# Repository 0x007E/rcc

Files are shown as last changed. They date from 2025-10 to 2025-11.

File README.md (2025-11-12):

   

# `RCC` - RGB Color Cube



The `RCC` project is based on a pcb with an [ATtiny402](#additional-information) and two [RGB LEDs](#additional-information) that are controlled via SPI-bus. The cube itself is controlled over a single push-button that enables/disables the cube and can be used to setup the color and intensity of the rgb leds.

| Experience | Level |
|:---|:-----:|
| Soldering | ?% |
| Mechanical  | ?% |
| Software | ?% |

# Manual

| Language | File | Description |
|:---:|:---:|:---:|
| English  | [pdf](https://github.com/0x007E/rcc/releases/latest/download/manual.en.pdf) | Assembly of PCB/housing and programming of the RCC |
| German | [pdf](https://github.com/0x007E/rcc/releases/latest/download/manual.de.pdf) | Assembly of PCB/housing and programming of the RCC |

# Simulator

With the [RCC-Simulator](https://0x007e.github.io/rcc-simulator/) different functions (e.g. power-on/-off, ...) can be simulated within a webpage.

# Downloads

| Type | File | Description |
|:---:|:---:|:---|
| Schematic | [pdf](https://github.com/0x007E/rcc/releases/latest/download/schematic.pdf) / [cadlab](https://cadlab.io/project/29642/main/files) | Schematic files |
| Board | [pdf](https://github.com/0x007E/rcc/releases/latest/download/pcb.pdf) / [cadlab](https://cadlab.io/project/29642/main/files) | Board file |
| Drill | [pdf](https://github.com/0x007E/rcc/releases/latest/download/drill.pdf) | Drill file |
| PCB | [zip](https://github.com/0x007E/rcc/releases/latest/download/kicad.zip) / [tar](https://github.com/0x007E/rcc/releases/latest/download/kicad.tar.gz) | KiCAD/Gerber/BoM/Drill files |
| Mechanical | [zip](https://github.com/0x007E/rcc/releases/latest/download/freecad.zip) / [tar](https://github.com/0x007E/rcc/releases/latest/download/freecad.tar.gz) | FreeCAD/Housing and PCB (STEP) files |
| Firmware | [zip](https://github.com/0x007E/rcc/releases/latest/download/firmware.zip) / [tar](https://github.com/0x007E/rcc/releases/latest/download/firmware.tar.gz) | Firmware for ATtiny402 |

# Hardware

There are two parts of the hardware. The pcb and the housing of the `RCC`. The pcb is created with [KiCAD](#additional-information) and the housing with `FreeCAD`. The software is programmed with [Microchip (Atmel) Studio](#additional-information). All files are built with `github actions` so that they are ready for a production environment. The housing is printed with a 3D-printer (`Dremel 3D40`).

## PCB

The circuit board is populated on both sides (Top, Bottom). The best way for soldering the `SMD` components is within a vapor phase soldering system and for the `THT` components with a standard soldering system.

### Top Layer

Top Layer

### Bottom Layer

Bottom Layer

## Mechanical

The housing has a tolerance of `0.2mm` on each side of the case. So the pcb should fit perfectly in the housing. The tolerance can be modified with `FreeCAD` in the `Parameter` Spreadsheet.

### Assembled

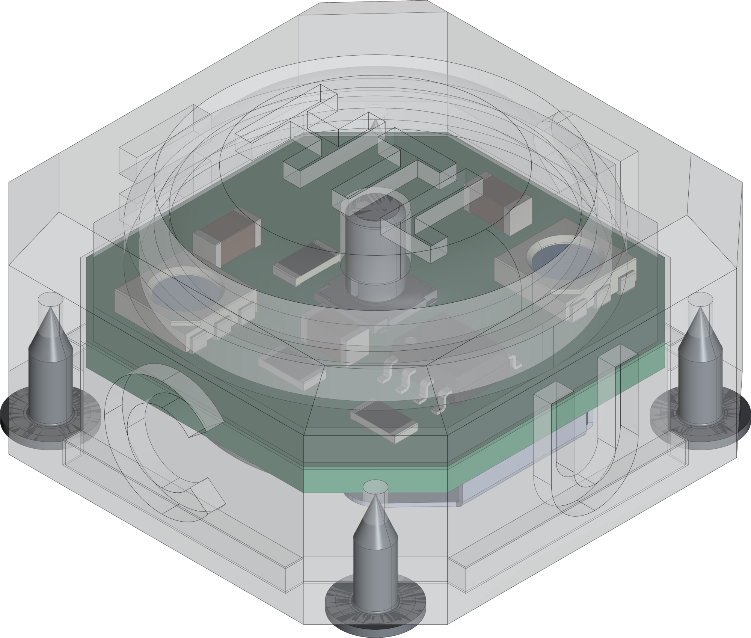
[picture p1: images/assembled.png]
Assembled


#### Exploded

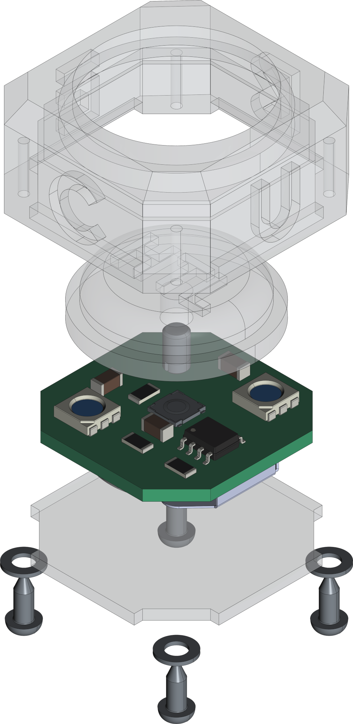
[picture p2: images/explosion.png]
Exploded


# Programming/Setup

The `RCC` is powerd with a `3V` battery (`CR2032`). It can be programmed over [UPDI](#additional-information) on `TP1`. The firmware for the cube can be downloaded in the [download section](#downloads).

``` bash
#                                                          +-----------+      +---------------------+
#                                                          |    U  +---+---+  |                     |
#     +---------------------+                              |    S  |  USB  |--+ +-----------------+ |
#     |                     |                              |    B  +---+---+  | | AVR-Dude        | |
#     |    RCC - Color Cube |         +----------+         |    /      |      | | ~~~~~~~~        | |
#     |                  +--+--+   +--+--+  U    |         |    U      |      | | ~~~~~           | |
#     |              VCC | TP3 +---+ VCC |  P  +--+--+  +--+--+ A      |      | | ~~~~~~~~~~~~    | |
#     |              GND | TP2 +---+ GND |  D  | GND +--+ GND | R      |      | |                 | |
#     |                  +--+--+   +--+--+  I  | VCC +--+ VCC | T      |      | +-----------------+ |
#     |                     |         |        +-----+  +-----+ A      |      |                     |
#     |                  +--+--+   +--+--+     | RxD +--+ RxD | +------+      | Computer            |
#     |             UPDI | TP1 +---+ PDI |     | TxD +--+ TxD | |5V/3V3|      |                     |
#     |                  +--+--+   +--+--+     +--+--+  +--+--+ +------+      +---------------------+
#     +---------------------+         | ADAPTER   |        +----+------+
#                                     +-----------+
```

## FUSES

| Register  | Value  |
|:---:|:---:|
| `WDTCFG`  | `0x00` |
| `BODCFG`  | `0x00` |
| `OSCCFG`  | `0x03` |
| `TCD0CFG` | `0x00` |
| `SYSCFG0` | `0xF5` |
| `SYSCFG1` | `0x00` |
| `APPEND`  | `0x00` |
| `BOOTEND` | `0x00` |

# Software

The leds are controlled by `SPI`. The interface is displayed in the [dataflow](#dataflow-diagram) diagram. There is a pre-configured firmware to use the cube or a library to implement own solutions.

> A documentation of the code can be found here [https://0x007e.github.io/rcc](https://0x007e.github.io/rcc).

## Dataflow diagram

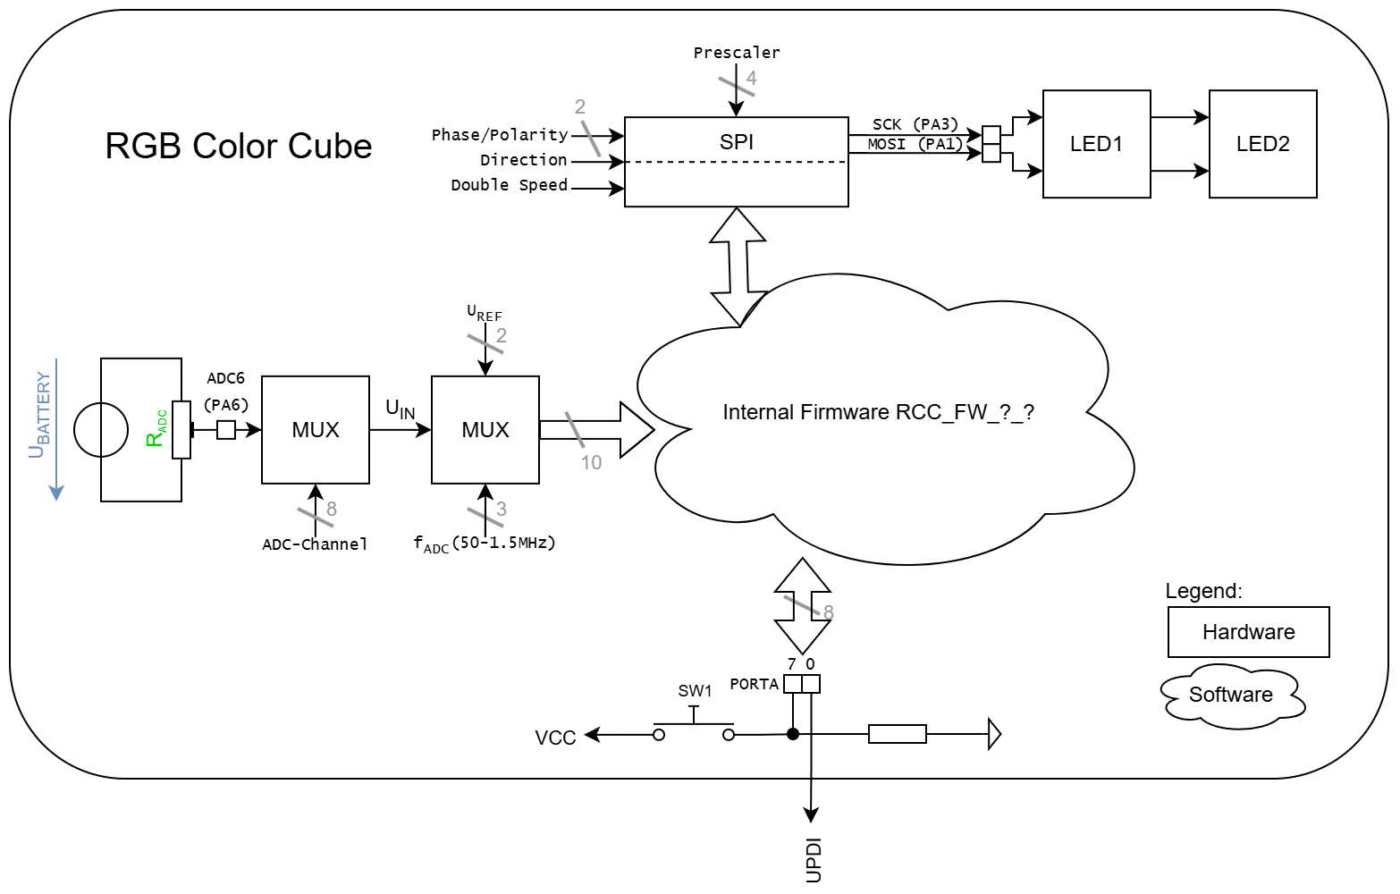
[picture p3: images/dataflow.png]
Dataflow


## Library (`led.h`)

With the attached `led` library it is quiet easy to use the cube for own implementations. To setup the led library for the cube implement the header file.

``` c
#define F_CPU 20000000UL

#include <avr/io.h>
#include <util/delay.h>

#include "./hal/avr0/system/system.h"
#include "./led/led.h"

LED_Data led1  = {
	0x01,
	0x0F,
	0x00,
	0x0A
};

LED_Data led2  = {
	0x01,
	0x00,
	0x0F,
	0x0A
};

int main(void)
{
    system_init();
    led_init();
    // ...

    while(1)
    {
        led_blink(LED_Position_Left | LED_Position_Right_Alternating, led_status_color(LED_Status_Ready, LED_MIN_INTENSITY), LED_Delay_MS_200, 2);

        LED_SOF();
        led_data(led1);
        led_data(led2);
        LED_EOF();

        _delay_ms(2000);
    }
}
```

# Additional Information

| Type | Link | Description |
|:---:|:---:|:---|
| ATtiny402  | [pdf](https://ww1.microchip.com/downloads/en/DeviceDoc/ATtiny202-402-AVR-MCU-with-Core-Independent-Peripherals_and-picoPower-40001969A.pdf) | ATtiny microcontroller |
| T3A33BRG | [pdf](https://mm.digikey.com/Volume0/opasdata/d220001/medias/docus/6794/3147_T3A33BRG-H9C0002X1U1930.pdf) | RGB Color LED |
| Atmel ICE  | [pdf](https://ww1.microchip.com/downloads/en/DeviceDoc/Atmel-ICE_UserGuide.pdf) | Atmel ICE datasheet |
| UPDI | [web](https://github.com/0x007e/updi) | UPDI-Adapter with AVR-Dude |
| Microchip Studio | [web](https://www.microchip.com/en-us/tools-resources/develop/microchip-studio) | Download page for Microchip Studio |
| KiCAD | [web](https://www.kicad.org/) | KiCAD project page |
| FreeCAD | [web](https://www.freecad.org/) | FreeCAD project page |

---

R. GAECHTER

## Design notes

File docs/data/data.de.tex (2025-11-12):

\newcommand{\headerText}{\textbf{HTL-Rankweil}\\\texttt{Abteilung für Elektronik/Informatik}}
\newcommand{\titleLogoCaption}{Zusammengesetzter Cube}
\newcommand{\titleDescription}{\small Das RCC-Projekt basiert auf einer Platine mit einem ATtiny402 und zwei RGB-LEDs, die über den SPI-Bus gesteuert werden. Der Cube selbst wird über einen einzigen Taster gesteuert, der den Cube ein- und ausschaltet und zur Einrichtung der Farbe und Helligkeit der LEDs verwendet werden kann.\\}

\newcommand{\globalimportanttext}{Wichtig:}

\newcommand{\abstracttitle}{Einleitung}
\newcommand{\abstracttext}{
Das \texttt{RCC}-Projekt (RGB LED Color Cube) ist ein eingebettetes System, das einen \texttt{ATtiny402}\footnote{\url{https://link.sunriax.at/MecTz}} Mikrocontroller, welcher zwei RGB-LEDs\footnote{\url{https://link.sunriax.at/nBUNH}} über einen SPI-Bus steuert, verwendet. Das System verfügt über eine Benutzeroberfläche mit einem einzigen Taster, um den \texttt{RCC}-Cube ein- und auszuschalten und die Farbe sowie die Helligkeitseinstellungen anzupassen. Es umfasst ein einfaches Hardware-Design, sowie eine Firmware und Bibliotheken für eine einfache Integration und Anpassung. Das Projekt nutzt KiCAD für das PCB-Design, FreeCAD für das Gehäuse und Microchip Studio für die bereitstellung der Firmware und legt dabei Wert auf Modularität und professionelle Produktionsbereitschaft durch automatisierte Build-Prozesse mit GitHub Actions. Dieses Setup bietet eine kompakte, vielseitige und programmierbare RGB-Beleuchtungslösung, die sich für Prototyping und Bildungszwecke in der Entwicklung von Elektronik- sowie eingebetteten Systemen eignet.
\newline
Die Montage der Leiterplatte erfolgt mit einer halbautomatischen Bestückungsmaschine, um eine präzise und effiziente Bauteilmontage sicherzustellen. Das Löten der Bauteile erfolgt mit einer Dampfphasenlötanalge, die eine gleichmäßige Wärmeverteilung und hochwertige Lötverbindungen gewährleistet. Das Batteriefach wird manuell mit herkömmlichen Lötmethoden (Bleifrei) verlötet. Das Gehäuse wird mittels 3D-Druck hergestellt, was eine schnelle Prototypenerstellung, eine hohe Genauigkeit und feine Details ermöglicht. Darüber hinaus wird die Acrylplatte auf der Unterseite des Gehäuses mit einem CO\textsubscript{2}-Laser-Cutter zugeschnitten und graviert, um präzise Formen und individuelle Oberflächenmarkierungen herzustellen.
\newline
Dieser Prozessablauf garantiert ein professionell montiertes und fertiges Produkt, das automatisierte Fertigungstechniken mit manueller Präzision und fortschrittlichen Fertigungstechnologien kombiniert.
}

\newcommand{\pcbsectiontitle}{Leiterplattenmontage}
\newcommand{\pcbfigureassemblytopcaptiontext}{Leiterplatten Top-Bearbeitungs- und Montagelayout}
\newcommand{\pcbfigureassemblybottomcaptiontext}{Leiterpatten Bottom-Bearbeitungs- und Montagelayout}

\newcommand{\programmersectiontitle}{Firmware-Programmierung}
\newcommand{\programmerfigureprogrammercaptiontext}{Programmer}
\newcommand{\programmerintroductiontext}{Die Verwendung des \texttt{Programmiergeräts} zum Flashen des \texttt{ATtiny402} über die \texttt{UPDI}-Schnittstelle ist unkompliziert. Die erforderliche Software zum Flashen kann über das \texttt{RCC Programming Repository}\footnote{\url{https://github.com/0x007e/rcc_programmer}} heruntergeladen werden. Über die USB-to-UART-Brücke wird die Firmware auf den Mikrocontroller übertragen. Die Anwendung selbst bietet eine einfache Benutzeroberfläche, um die Firmware auf den \texttt{RCC} zu übertragen. Die Farbe und die Intensität der LEDs kann innerhalb der Anwendung angepasst werden.}
\newcommand{\programmertabledownloadlinkstitle}{RCC - Programmier-Software (Windows x64)}
\newcommand{\programmertabledownloadlinksclickoncetext}{ClickOnce-Installer, der automatisch aktualisiert wird, wenn neue Versionen verfügbar sind.}
\newcommand{\programmertabledownloadlinksportabletext}{Portable Version, die ohne Installation ausgeführt werden kann, aber manuell aktualisiert werden muss.}
\newcommand{\programmertabledownloadlinkscaptiontext}{Download-Links}
\newcommand{\programmerfigureinterfacecaptiontext}{Programmierschnittstelle}
\newcommand{\programmertablenoticetext}{Der \textbf{RCC}-Cube wird durch die USB-UART-Brücke (über die \texttt{Pogo}-Pins) mit \texttt{3V3} versorgt und benötigt keine Batterie. Es ist sicherzustellen, dass das \textbf{RCC}-Gerät \textbf{\textcolor{red}{nicht mit Batterie betrieben wird, um Schäden am Gerät zu vermeiden!}}}
\newcommand{\programmertablenoticecaption}{Programmiergerät-Hinweis}
\newcommand{\programmertableselfmadeupdititle}{Verwenden von externen UPDI-Adaptern}
\newcommand{\programmertableselfmadeupditext}{Ein selbstgebauter UPDI-Adapter kann auch innerhalb einer FT232 USB-to-UART-Brücke oder eines ähnlichen Moduls gemäß den Schaltplänen auf der \texttt{UPDI}\footnote{\url{https://github.com/0x007e/updi}}-Projektseite verwendet werden. Die Verbindungsanordnung finden Sie auf der Programmierer-Projektseite\footnote{\url{https://github.com/0x007e/rcc_programmer}} selbst.}
\newcommand{\programmertableselfmadeupdicaption}{UPDI-Adapter-Informationen}

\newcommand{\mechanicalsectiontitle}{Mechanische Montage}
\newcommand{\mechanicalintroductiontext}{Die mechanische Montage erfolgt durch das Zusammenfügen der 3D-gedruckten Gehäuseteile mit der lasergeschnittenen Acrylplatte. Die Leiterplatte wird mit den integrierten Montageschrauben im Gehäuse befestigt. Die Batterie muss montiert werden, bevor die Leiterplatte im Gehäuse platziert wird.}
\newcommand{\mechanicalsubsectionsteps}{Notwendige Schritte:}
\newcommand{\mechanicalfigurecaptionexplosion}{Explosionsansicht der mechanischen Montage}

\newcommand{\mechanicaltextfile}{./data/mechanicaltext.de.csv}
\newcommand{\mechanicalstepsfile}{./data/mechanicalsteps.de.csv}

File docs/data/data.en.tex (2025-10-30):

\newcommand{\headerText}{\textbf{HTL-Rankweil}\\\texttt{Department of Electronics/Informatics}}
\newcommand{\titleLogoCaption}{Assembled Cube}
\newcommand{\titleDescription}{\small The RCC project is based on a pcb with an ATtiny402 and two RGB LEDs that are controlled via SPI-bus. The cube itself is controlled over a single push-button that enables/disables the cube and can be used to setup the color and intensity of the leds.\\}

\newcommand{\globalimportanttext}{Important:}

\newcommand{\abstracttitle}{Abstract}
\newcommand{\abstracttext}{
The \texttt{RCC} (RGB LED Color Cube) project is an embedded system based on a PCB with an \texttt{ATtiny402}\footnote{\url{https://link.sunriax.at/MecTz}} microcontroller controlling two RGB LEDs\footnote{\url{https://link.sunriax.at/nBUNH}} via SPI communication. The system features a user interface with a single push-button to toggle the cube and adjust its color and brightness settings. It includes comprehensive hardware designs, firmware, and libraries for easy integration and customization. The project leverages KiCAD for PCB design, FreeCAD for housing, and Microchip Studio for firmware development, emphasizing modularity and professional production readiness through automated build processes using GitHub Actions. This setup provides a compact, versatile, and programmable RGB lighting solution suitable for prototyping and educational purposes in electronic and embedded systems development.
\newline
The assembly of the PCB is carried out using a semi-automatic placement machine to ensure precise and efficient component mounting. Soldering of the PCB components is performed with a vapor phase soldering system, which provides uniform heat distribution and high-quality solder joints. The battery holder is soldered manually using conventional soldering methods to allow for careful handling of this specific component. The enclosure is produced by 3D printing, enabling rapid prototyping with high accuracy and fine detail. Additionally, the acrylic plate on the bottom side of the enclosure is cut and engraved using a CO\textsubscript{2} laser cutter, ensuring precise shaping and custom surface markings.
\newline
This process guarantees a professionally assembled and finished product combining automated manufacturing techniques with manual precision and advanced fabrication technologies.
}

\newcommand{\pcbsectiontitle}{PCB Assembly}
\newcommand{\pcbfigureassemblytopcaptiontext}{PCB Top fabrication and assembly layout}
\newcommand{\pcbfigureassemblybottomcaptiontext}{PCB Bottom fabrication and assembly layout}

\newcommand{\programmersectiontitle}{Firmware programming}
\newcommand{\programmerfigureprogrammercaptiontext}{Programmer}
\newcommand{\programmerintroductiontext}{Using the \texttt{programming tool} to flash the \texttt{ATtiny402} via \texttt{UPDI} interface is straightforward. Just download and install the required software and flash it with the \texttt{RCC Programming Toolkit}\footnote{\url{https://github.com/0x007e/rcc_programmer}} over the implemented USB-to-UART bridge in the \texttt{RCC-Programmer}. The \texttt{programming tool} itself can be installed or used as a portable application. The application itself provides a simple user interface to flash the firmware onto the \texttt{RCC} device. Therefore the color and intensitry of the LEDs can be adjusted within the application before flashing it onto the device.}
\newcommand{\programmertabledownloadlinkstitle}{RCC - Programming Software (Windows x64)}
\newcommand{\programmertabledownloadlinksclickoncetext}{ClickOnce installer that updates automatically when new versions are available.}
\newcommand{\programmertabledownloadlinksportabletext}{Portable version that can be run without installation but needs to be updated manually.}
\newcommand{\programmertabledownloadlinkscaptiontext}{Download Links}
\newcommand{\programmerfigureinterfacecaptiontext}{Programming Interface}
\newcommand{\programmertablenoticetext}{The \textbf{RCC}-Cube is powered through the USB-UART bridge (through the \texttt{Pogo}-pins) with \texttt{3V3} and does not require a battery. It must be ensured that the \textbf{RCC} device is \textbf{\textcolor{red}{not powered by battery to avoid damage to the device!}}}
\newcommand{\programmertablenoticecaption}{Programmer Notice}
\newcommand{\programmertableselfmadeupdititle}{Using of external UPDI-Adapters}
\newcommand{\programmertableselfmadeupditext}{A selfmade UPDI adapter can also be used within an FT232 USB-to-UART bridge or a similar module according to the schematics provided on the \texttt{UPDI}\footnote{\url{https://github.com/0x007e/updi}} project page. The connection setup can be found on the programmer project site\footnote{\url{https://github.com/0x007e/rcc_programmer}} itself.}
\newcommand{\programmertableselfmadeupdicaption}{UPDI-Adapter Information}

\newcommand{\mechanicalsectiontitle}{Mechanical Assembly}
\newcommand{\mechanicalintroductiontext}{The mechanical assembly is done by assembling the 3D printed enclosure parts together with the laser-cut acrylic plate. The PCB is mounted inside the enclosure using the integrated mounting features. The battery has to be mounted before the PCB is placed inside the enclosure.}
\newcommand{\mechanicalsubsectionsteps}{Necessary steps:}
\newcommand{\mechanicalfigurecaptionexplosion}{Exploded view of the mechanical assembly}

\newcommand{\mechanicaltextfile}{./data/mechanicaltext.en.csv}
\newcommand{\mechanicalstepsfile}{./data/mechanicalsteps.en.csv}

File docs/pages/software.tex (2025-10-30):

\newcounter{softwaretnotecounter}

\iflanguage{ngerman}{
  \newcommand{\softwaresectiontitle}{Verwendete Software}
  \newcommand{\softwaretableimage}{Abbildung}
  \newcommand{\softwaretablename}{Name}
  \newcommand{\softwaretabledescription}{Beschreibung}
  \newcommand{\softwaretablecaptiontext}{Softwarekomponenten für das Projekt}

  \newcommand{\softwareltspicetext}{Simulationssoftware für elektronische Schaltungen, weitverbreitet zum Entwurf und Testen von Schaltungen.}
  \newcommand{\softwaremicrochipstudiotext}{Entwicklungsumgebung (IDE) zur Programmierung von Mikrocontrollern, insbesondere AVR und ARM.}
  \newcommand{\softwarefreecadtext}{Open-Source CAD-Software für 3D-Modellierung, geeignet für technische Konstruktionen und Design.}
  \newcommand{\softwarekicadtext}{Open-Source PCB-Design-Software, geeignet für die Erstellung von Leiterplattenlayouts.}
  \newcommand{\softwaredremeldigilabslicertext}{Software zum Vorbereiten und Slicen von 3D-Druck-Modellen, speziell für Dremel 3D-Drucker optimiert.}

  \newcommand{\softwarelogotext}{Die abgebildeten Logos sind markenrechtlich geschützte Symbole. Sie werden in dieser Dokumentation ausschließlich zur Identifikation der jeweiligen Softwareprodukte verwendet, ohne Werbeabsicht.}
}{
  \newcommand{\softwaresectiontitle}{Used Software}
  \newcommand{\softwaretableimage}{Figure}
  \newcommand{\softwaretablename}{Name}
  \newcommand{\softwaretabledescription}{Description}
  \newcommand{\softwaretablecaptiontext}{Software components for the project}

  \newcommand{\softwareltspicetext}{Simulation software for electronic circuits, widely used for designing and testing circuits.}
  \newcommand{\softwaremicrochipstudiotext}{Development environment (IDE) for programming microcontrollers, especially AVR and ARM.}
  \newcommand{\softwarefreecadtext}{Open-source CAD software for 3D modeling, suitable for technical constructions and design.}
  \newcommand{\softwarekicadtext}{Open-source PCB design software, suitable for creating printed circuit board layouts.}
  \newcommand{\softwaredremeldigilabslicertext}{Software for preparing and slicing 3D print models, specifically optimized for Dremel 3D printers.}

  \newcommand{\softwarelogotext}{The logos shown are protected by trademark law. They are used in this documentation solely for the identification of the respective software products, without any advertising intent.}
}

\section*{\softwaresectiontitle}
\begin{table}[!ht]
  \renewcommand{\arraystretch}{1.3}
  \centering
  \begin{threeparttable}
    \begin{tabularx}{\linewidth}{|M{2.4cm}|M{2.2cm}|X|}
      \hline
      \rowcolor{gray!20}
      \textbf{\softwaretableimage\tnote{*}} & \textbf{\softwaretablename} & \textbf{\softwaretabledescription} \\
      \hline
\ifsoftwarepagelineartechnology
      \stepcounter{softwaretnotecounter}
      \raisebox{-.25\height}{\includesvg[width=1.6cm,inkscapelatex=false]{./logo/linear_technology}} &
      LT-Spice\tnote{(\thesoftwaretnotecounter)} &
      \softwareltspicetext\\
      \hline
\fi
\ifsoftwarepagemicrochipstudio
      \stepcounter{softwaretnotecounter}
      \raisebox{-.25\height}{\includesvg[width=1.6cm,inkscapelatex=false]{./logo/microchip}} &
      Microchip Studio\tnote{(\thesoftwaretnotecounter)} &
      \softwaremicrochipstudiotext\\
      \hline
\fi
\ifsoftwarepagefreecad
      \stepcounter{softwaretnotecounter}
      \raisebox{-.25\height}{\includesvg[width=0.65cm,inkscapelatex=false]{./logo/freecad}} &
      FreeCAD\tnote{(\thesoftwaretnotecounter)} &
      \softwarefreecadtext\\
      \hline
\fi
\ifsoftwarepagekicad
      \stepcounter{softwaretnotecounter}
      \raisebox{-.25\height}{\includesvg[width=0.65cm,inkscapelatex=false]{./logo/kicad}} &
      KiCAD\tnote{(\thesoftwaretnotecounter)} &
      \softwarekicadtext\\
      \hline
\fi
\ifsoftwarepagedremeldigilabslicer
      \stepcounter{softwaretnotecounter}
      \raisebox{-.25\height}{\includesvg[width=1.6cm,inkscapelatex=false]{./logo/dremel}} &
      Dremel 3D DigiLab Slicer\tnote{(\thesoftwaretnotecounter)} &
      \softwaredremeldigilabslicertext\\
      \hline
\fi
    \end{tabularx}
    \caption{\softwaretablecaptiontext}
    \label{tab:software-programme}
    \begin{tablenotes}
      \footnotesize
      \item[*] \softwarelogotext
      \item[~]
\setcounter{softwaretnotecounter}{0}
\ifsoftwarepagelineartechnology
      \stepcounter{softwaretnotecounter}
      \item[(\thesoftwaretnotecounter)] \url{https://www.analog.com/en/resources/design-tools-and-calculators.html}
\fi
\ifsoftwarepagemicrochipstudio
      \stepcounter{softwaretnotecounter}
      \item[(\thesoftwaretnotecounter)] \url{https://www.microchip.com/en-us/tools-resources/develop/microchip-studio}
\fi
\ifsoftwarepagefreecad
      \stepcounter{softwaretnotecounter}
      \item[(\thesoftwaretnotecounter)] \url{https://www.freecad.org/downloads.php}
\fi
\ifsoftwarepagekicad
      \stepcounter{softwaretnotecounter}
      \item[(\thesoftwaretnotecounter)] \url{https://www.kicad.org/download/}
\fi
\ifsoftwarepagedremeldigilabslicer
      \stepcounter{softwaretnotecounter}
      \item[(\thesoftwaretnotecounter)] \url{https://www.dremel.com/at/de/digilab/3d-druckersoftware}  
\fi
    \end{tablenotes}
  \end{threeparttable}
\end{table}

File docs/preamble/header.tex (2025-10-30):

% Paket für Kopf- und Fußzeilen
\usepackage[automark,headsepline=0.4pt:1.0\textwidth,footsepline=0.4pt:1.0\textwidth]{scrlayer-scrpage}
% Paket für Gesamtseitenzahl
\usepackage{lastpage}

\pagestyle{scrheadings}     % Kopf- und Fußzeilen-Stil setzen

% Standard-Stile von Kopf- und Fußzeilen entfernen
\clearpairofpagestyles

\ihead{}
\chead{}
\ohead{
  \parbox[t]{15cm}{
    \raggedleft
    \headerText
  }
}

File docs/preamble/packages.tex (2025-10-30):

% Sprach- und Kodierungspakete
\usepackage[utf8]{inputenc}
\usepackage[english,ngerman]{babel}
\usepackage[T1]{fontenc}
\usepackage{graphicx}
\usepackage{expl3,xparse}

% Seitenränder
\usepackage[a4paper,margin=2.5cm,top=80pt,headheight=55pt,headsep=10pt,footskip=35pt]{geometry}

% Zeilenabstand
%\usepackage{setspace}
\usepackage[onehalfspacing]{setspace}
\usepackage{array}

\usepackage[colorlinks=true,linkcolor=black,urlcolor=blue,citecolor=black]{hyperref}
\usepackage{url}
\usepackage[nolinks]{qrcode}

\usepackage[printonlyused]{acronym}
\usepackage{tabularx}
\usepackage{tablefootnote}
\usepackage{multirow}
\usepackage{wrapfig}
\usepackage{threeparttable}
\usepackage[table]{xcolor}
\usepackage{tikz}
\usepackage{microtype}
\usepackage{svg}
\usepackage{pifont}

\usepackage{caption}

\usepackage{enumitem}
\setlist[itemize]{itemsep=0.025em}

\usepackage{csquotes}
\usepackage[style=apa, backend=biber]{biblatex}
\addbibresource{./literature.bib}

\usepackage[l3]{csvsimple}

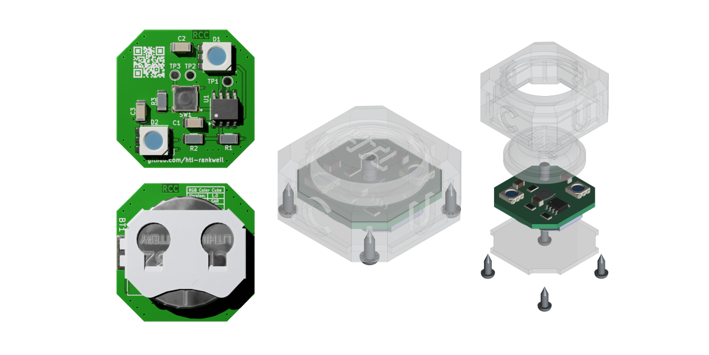
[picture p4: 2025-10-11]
images/social.png

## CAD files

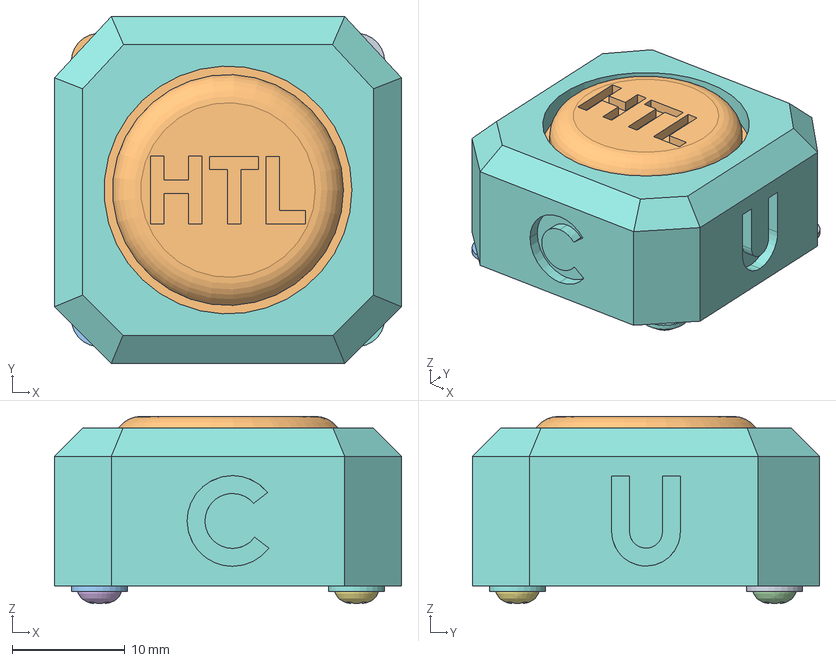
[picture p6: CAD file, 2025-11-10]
mechanical/housing.FCStd
30.8 x 30.8 x 16.6 mm
Pcb_1096
R2_R_1206_3216Metric_a244ae71ee7f
D2_LED_RGB_5050_6_3082613c1204
C2_C_1206_3216Metric_b2c0b2178a0f
C3_C_1206_3216Metric_2d6a083c182e
U1_SOIC_8_39x49mm_P127mm_ced3e6da737e
SW1_1_b49bc00616b6
R3_R_1206_3216Metric_352e77470e97
C1_C_1206_3216Metric_55e30c71a8e1
R1_R_1206_3216Metric_4fa9a57fca02
D1_LED_RGB_5050_6_e07a5316f1e2
BH-67D-5_BH-67D-5
Acrylglass
Button
M3x5-Screw
ST2.2x6.5-Screw
ST2.2x6.5-Screw493
ST2.2x6.5-Screw494
ST2.2x6.5-Screw495
M2.5-Washer
M2.5-Washer022
M2.5-Washer023
M2.5-Washer024

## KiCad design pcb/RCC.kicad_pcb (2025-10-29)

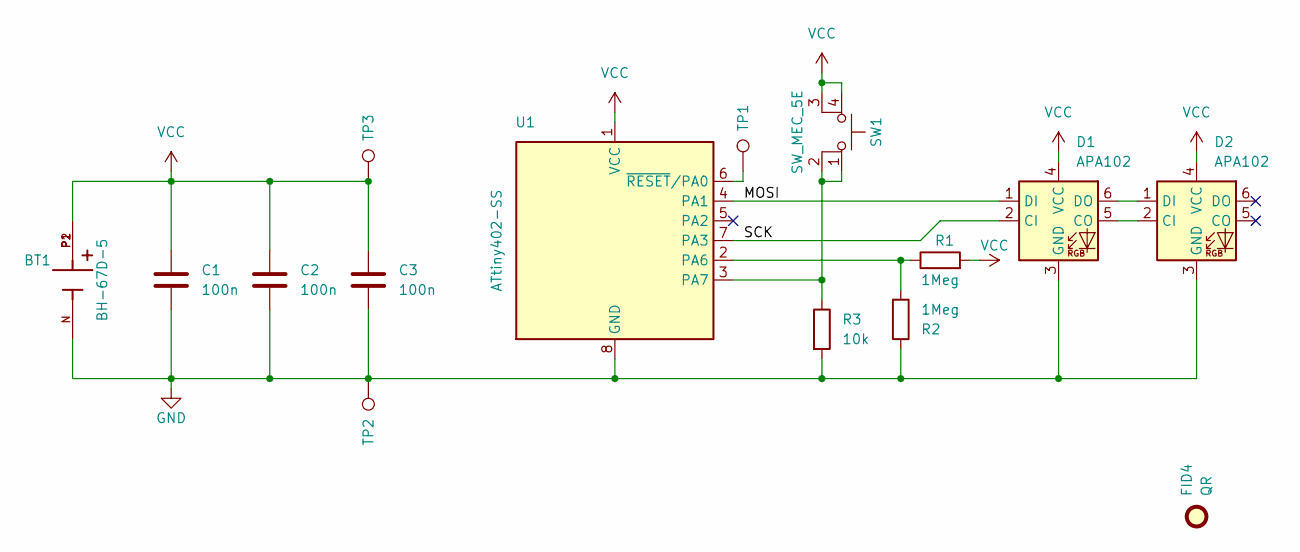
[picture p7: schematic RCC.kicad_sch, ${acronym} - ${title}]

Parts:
BT1: BH-67D-5; BAT_BH-67D-5
C1, C2, C3: 100n; C_1206_3216Metric
D1, D2: APA102; LED_RGB_5050-6
FID4: QR; QR_0x007e_small
R1, R2: 1Meg; R_1206_3216Metric
R3: 10k; R_1206_3216Metric
SW1: SW_MEC_5E; SW_PTS530_GK055_SMTR_LFS
TP1, TP2, TP3: TestPoint; TestPoint_Pad_D1.5mm
U1: ATtiny402-SS; SOIC-8_3.9x4.9mm_P1.27mm

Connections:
/MOSI: D1.1 (DI), U1.4 (PA1)
/SCK: D1.2 (CI), U1.7 (PA3)
GND: BT1.N, C1.2, C2.2, C3.2, D1.3 (GND), D2.3 (GND), R2.1, R3.2, TP2.1, U1.8 (GND)
unnamed: D1.5 (CO), D2.2 (CI)
unnamed: D1.6 (DO), D2.1 (DI)
unnamed: R1.1, R2.2, U1.2 (PA6)
unnamed: R3.1, SW1.1, SW1.2, U1.3 (PA7)
unnamed: TP1.1, U1.6 (~RESET/PA0)
VCC: BT1.P1, BT1.P2, C1.1, C2.1, C3.1, D1.4 (VCC), D2.4 (VCC), R1.2, SW1.3 (K), SW1.4 (A), TP3.1, U1.1 (VCC)

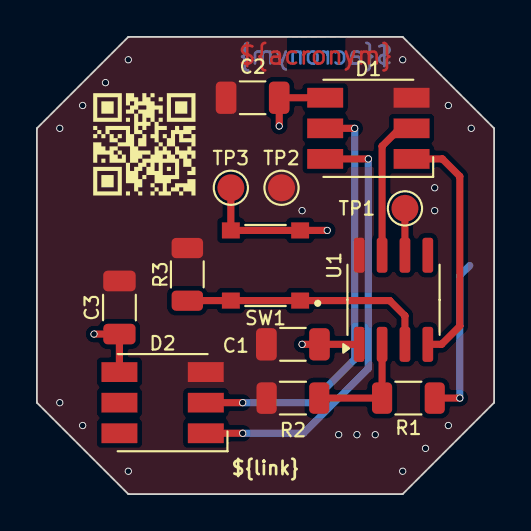
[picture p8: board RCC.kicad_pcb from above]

Board: 2 copper layers, 25.4 x 25.4 mm, 15 parts (1 on the bottom side), 9 nets.

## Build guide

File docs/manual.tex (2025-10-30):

\documentclass[a4paper,12pt]{scrartcl}

\input{./preamble/packages.tex}
\input{./preamble/branch.tex}

\usepackage{listings}

% Globale Parameter
\setlength{\parindent}{0pt} % Kein Einrücken am Anfang eines Absatzes
\newcommand{\documentAuthor}{R. GÄCHTER}

% Header-Parameter
\headertrue           % Header aktivieren
  \newcommand{\headerLogo}{./images/htl.png}

% Footer-Parameter
\footertrue           % Footer aktivieren
  \newcommand{\footerAuthor}{\documentAuthor}
  \newcommand{\footerVersion}{1.0}

% Page-Parameter
% \acronymspagetrue         % Acronyme aktivieren
% \tableofcontentspagetrue  % Inhaltsverzeichnis aktivieren
\listoffigurespagetrue    % Abbildungsverzeichnis aktivieren
\listoftablespagetrue     % Tabellenverzeichnis aktivieren
% \bibliographypagetrue     % Literaturverzeichnis aktivieren

% Titlepage-Parameter
\titlepagetrue                  % Titelblatt aktivieren
\titlepageqrcodetrue            % QR-Code auf dem Titelblatt aktivieren
% \blankpageaftertitlepagetrue  % Leerseite nach dem Titelblatt aktivieren
  \newcommand{\titleHeadline}{RCC - RGB LED Color Cube}
  \newcommand{\titleLogo}{./images/assembled.png}
  \newcommand{\titleLogoWidth}{0.35}
  \newcommand{\titleRepository}{https://github.com/0x007e/rcc}

% Softwarepage-Parameter
\softwarepagetrue     % Software-Seite aktivieren
  % \softwarepagelineartechnologytrue
  \softwarepagemicrochipstudiotrue
  \softwarepagefreecadtrue
  \softwarepagekicadtrue
  % \softwarepagedremeldigilabslicertrue

\input{./preamble/tabular.tex}
\input{./preamble/commands.tex}

\ifheader
  \input{./preamble/header.tex}
\fi

\iffooter
  \input{./preamble/footer.tex}
\fi

% ##########################################################################

\begin{document}

% \selectlanguage{ngerman}
% \selectlanguage{english}

\renewcommand{\tablename}{Tab.}

\iflanguage{ngerman}{
  \renewcommand{\figurename}{Abb.}
  \input{./data/data.de.tex}
}{
  \renewcommand{\figurename}{Fig.}
  \input{./data/data.en.tex}
}

\iftitlepage
  \input{./pages/titlepage.tex}
  \maketitle

  \thispagestyle{empty}
  \newpage

  \ifblankpageaftertitlepage
    ~
    \thispagestyle{empty}
    \newpage
  \fi
\fi

\ifsoftwarepage
  \input{./pages/software.tex}

  \thispagestyle{empty}
  \newpage
\fi

\section*{\abstracttitle}
\abstracttext

\thispagestyle{empty}
\newpage

\setcounter{page}{1}

\noindent\hfill\texttt{GAR@\today|\jobname.pdf}
\vspace{-25pt}

\section{\pcbsectiontitle}

\begin{figure}[!htbp]
  \vspace{-20pt}
  \centering
  
  \caption{\pcbfigureassemblytopcaptiontext}
  \label{fig:pcb-top-assembly}
\end{figure}
\newpage

\begin{figure}[!htbp]
  \centering
  
  \caption{\pcbfigureassemblybottomcaptiontext}
  \label{fig:pcb-bottom-assembly}
\end{figure}
\newpage

\section{\programmersectiontitle}

\begin{wrapfigure}{r}{0.25\textwidth}
  \vspace{-50pt}
  
  \caption{\programmerfigureprogrammercaptiontext}
  \label{fig:rcc-programmer-image}
\end{wrapfigure}

\programmerintroductiontext

\begin{table}[!htbp]
  \renewcommand{\arraystretch}{1.2}
  \noindent
  \begin{minipage}{\textwidth}
    \begin{tabularx}{\textwidth}{|c|c|X|}
      \hline
      \rowcolor{gray!20}
      \multicolumn{3}{|c|}{\textbf{\programmertabledownloadlinkstitle}} \\
      \hline
      \multirow{2}{*}{
        \raisebox{-.5\height}{
          
        }
      } & 
      \href{https://0x007e.github.io/rcc_programmer/clickonce/setup.exe}{\textbf{Installer}}\footnote{\url{https://0x007e.github.io/rcc_programmer/clickonce/setup.exe}} &
      \programmertabledownloadlinksclickoncetext \\
      \cline{2-3}
       & \href{https://github.com/0x007E/rcc_programmer/releases/latest/download/programmer.zip}{\textbf{Portable}}\footnote{\url{https://github.com/0x007E/rcc_programmer/releases/latest/download/programmer.zip}} &
      \programmertabledownloadlinksportabletext \\
      \hline
    \end{tabularx}
    \caption{\programmertabledownloadlinkscaptiontext}
    \label{tab:rcc-programming-download-links}
  \end{minipage}
\end{table}

\vspace{-15pt}
\begin{table}[!htbp]
  \renewcommand{\arraystretch}{1.2}
  \noindent
  \begin{minipage}[t]{0.55\textwidth}
    \vspace{0pt}
    \centering
    
    \caption{\programmerfigureinterfacecaptiontext}
    \label{fig:rcc-programming-interface}
  \end{minipage}%
  \hfill
  \begin{minipage}[t]{0.42\textwidth}
    \vspace{0pt}
    \centering
    \begin{tabularx}{\textwidth}{|M{0.85cm}|X|}
      \hline
      \rowcolor{gray!20}
      \raisebox{-.25\height}{\includesvg[height=0.55cm,inkscapelatex=false]{./symbol/warning}} & \textbf{\globalimportanttext} \\
      \hline
      \multicolumn{2}{|p{\dimexpr\textwidth-2\tabcolsep}|}{\programmertablenoticetext} \\
      \hline
    \end{tabularx}
    \caption{\programmertablenoticecaption}
    \label{tab:rcc-programmer-notice}
  \end{minipage}
\end{table}

\vspace{-10pt}
\begin{table}[!ht]
  \renewcommand{\arraystretch}{1.2}
  \centering
  \begin{tabularx}{\textwidth}{|M{0.85cm}|X|}
      \hline
      \rowcolor{gray!20}
      \raisebox{-.25\height}{\includesvg[height=0.55cm,inkscapelatex=false]{./symbol/info}} & \textbf{\programmertableselfmadeupdititle} \\
      \hline
      \multicolumn{2}{|p{\dimexpr\textwidth-2\tabcolsep}|}{\programmertableselfmadeupditext} \\
  \hline
  \end{tabularx}
  \caption{\programmertableselfmadeupdicaption}
  \label{tab:rcc-programmer-selfmade-updi}
\end{table}

\newpage

\section{\mechanicalsectiontitle}
\mechanicalintroductiontext
\subsection*{\mechanicalsubsectionsteps}

\begin{itemize}
  \setlength\itemsep{-5pt}
  \setlength\parskip{5pt}
  \csvreader[head to column names]{\mechanicalstepsfile}{}
  {
    \item \itemtext
  }
\end{itemize}

\begin{figure}[htb]
  \vspace{-15pt}
  \centering
  
  \caption{\mechanicalfigurecaptionexplosion}
  \label{fig:mechanical-explosion}
\end{figure}
\newpage

\iflistoffigurespage
  \listoffigures
\fi

\iflistoftablespage
  \listoftables
\fi

\iflistoffigurespage
  \thispagestyle{empty}
  \newpage
\else
  \iflistoftablespage
    \thispagestyle{empty}
    \newpage
  \fi
\fi

\end{document}

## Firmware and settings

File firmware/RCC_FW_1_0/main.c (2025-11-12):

/**
 * @file main.c
 * @brief Main firmware file for RCC RGB LED Color Cube on AVR.
 *
 * This source file implements the main control flow and event handling for the RCC embedded system. It manages system initialization, LEDs and battery management, interrupt handling, EEPROM operations, and execution of user commands triggered by button inputs. Key functionalities include timed LED blinking, system-wide power management including shutdown and restart logic, and processing of button press events for dynamic LED control.
 *
 * @author g.raf
 * @date 2025-12-10
 * @version 1.0 Release
 * @copyright
 * Copyright (c) 2025 g.raf
 * Released under the GPLv3 License. (see LICENSE in repository)
 *
 * @note This file is part of a larger AVR embedded project subject to the license specified in the repository. For updates and complete revision history, see the GitHub repository.
 *
 * @see https://github.com/0x007e/rcc "RCC - RGB LED Color Cube"
 */

#include "main.h"

static unsigned int switch_count = 0UL;

char EEMEM description[] = "RCC Firmware v1.0 by";
char EEMEM author[] = "R. GAECHTER";
char EEMEM copyright[] = "Copyright 2025 g.raf engineering";
char EEMEM github[] = "github.com/0x007e/rcc";

LED_Data EEMEM ee_led1  = {
	0x03,
	0x00,
	0xFF,
	0xFF
};

LED_Data EEMEM ee_led2  = {
	0x03,
	0xFF,
	0x00,
	0xFF
};

LED_Data led1, led2;

/**
 * @brief Interrupt Service Routine for PORTA pin change or event.
 *
 * This ISR handles the interrupt triggered by an event on PORTA pins. In this implementation, it only clears the interrupt flag for PIN7 on PORTA to acknowledge and allow further interrupts. This prevents the interrupt from continuously retriggering.
 *
 * @note The ISR is registered for the PORTA interrupt vector and is executed automatically upon the corresponding hardware interrupt and is necessary for system wakeup after deep sleep.
 */
ISR(PORTA_PORT_vect)
{	
	PORTA.INTFLAGS = PORT_INT_7_bm;
}

volatile unsigned long systick;

/**
 * @brief Timer/Counter Overflow Interrupt Service Routine.
 *
 * This ISR is called when the Timer/Counter overflows. It increments the global millisecond tick counter `systick` used for system timing. The interrupt flag for the overflow is cleared to allow subsequent interrupts.
 *
 * @note Ensure the timer is properly configured and overflow interrupts are enabled for this routine to be executed correctly.
 */
ISR(TCA0_OVF_vect)
{
    systick++;
	TCA0.SINGLE.INTFLAGS = TCA_SINGLE_OVF_bm;
}

/**
 * @brief Initializes Timer/Counter in single mode with overflow interrupt.
 *
 * This function configures the TCA0 timer as a 16-bit timer operating in single mode. It sets the overflow interrupt enable bit, loads the period register with a predefined value, and starts the timer with a clock prescaler of divide-by-8.
 *
 * @details
 * The timer will generate an interrupt when the counter overflows at the value in the PER register. The overflow interrupt is enabled to allow time-based events or system ticks. The clock source selection and enabling the timer starts the counting immediately.
 */
static void timer_init(void)
{	
	TCA0.SINGLE.INTCTRL |= TCA_SINGLE_OVF_bm;
	TCA0.SINGLE.PER = 0x04E1;
	TCA0.SINGLE.CTRLA |= TCA_SINGLE_CLKSEL_DIV8_gc | TCA_SINGLE_ENABLE_bm;
}

/**
 * @brief Disables Timer/Counter and clears its overflow interrupt.
 *
 * This function disables the overflow interrupt for Timer/Counter TCA0, stops the timer by clearing the clock select and enable bits, and clears any pending overflow interrupt flags.
 *
 * @details
 * Disabling the timer halts counting and prevents further interrupt triggers. The interrupt flag is cleared to avoid immediately re-entering the ISR. This should be called when timer-based operations need to be stopped safely.
 */
static void timer_disable(void)
{
	TCA0.SINGLE.INTCTRL &= ~TCA_SINGLE_OVF_bm;
	TCA0.SINGLE.CTRLA = ~(TCA_SINGLE_CLKSEL_DIV8_gc | TCA_SINGLE_ENABLE_bm);
	TCA0.SINGLE.INTFLAGS = TCA_SINGLE_OVF_bm;
}

/**
 * @brief Performs a controlled system shutdown and restarts the microcontroller.
 *
 * This function disables timers, battery and LED subsystems, configures PORTA pins for low power, sets the microcontroller into the power-down sleep mode to minimize energy consumption, and then triggers a software reset to restart the system.
 *
 * @details
 * - Disables the Timer/Counter to stop timing interrupts
 * - Powers down battery and LED to save energy
 * - Configures PORTA pins as inputs with pull-ups or specific sensing modes
 * - Puts the CPU to sleep in the deepest power save mode (PWR_DOWN)
 * - After waking up (unlikely unless interrupt occurs), disables sleep and interrupts
 * - Triggers a software reset via the Reset Control register (RSTCTRL)
 *
 * This ensures a safe and clean shutdown and restart sequence on AVR microcontrollers.
 */
static void system_shutdown(void)
{
    // System Shutdown
    timer_disable();
    battery_disable();
    led_disable();

    PORTA.DIRCLR = PIN7_bm | PIN6_bm | PIN3_bm | PIN2_bm | PIN1_bm | PIN0_bm;
    PORTA.PIN7CTRL =  PORT_ISC_BOTHEDGES_gc;
    PORTA.PIN6CTRL =  PORT_PULLUPEN_bm;
    PORTA.PIN3CTRL =  PORT_PULLUPEN_bm;
    PORTA.PIN2CTRL =  PORT_PULLUPEN_bm;
    PORTA.PIN1CTRL =  PORT_PULLUPEN_bm;
    PORTA.PIN0CTRL =  PORT_PULLUPEN_bm;
    PORTA.INTFLAGS = PORT_INT_7_bm;

    set_sleep_mode(SLEEP_MODE_PWR_DOWN);
    sleep_enable();
    sei();
    sleep_cpu();

    sleep_disable();
    cli();

    // Restart System
    CCP = CCP_IOREG_gc;
    RSTCTRL.SWRR = RSTCTRL_SWRE_bm;
}

static unsigned long last_button_press;
static unsigned char execute_command;

int main(void)
{
    system_init();
    led_init();
	battery_init();
	
    if(battery_status() == BATTERY_Ok)
    {
        led_blink(LED_Position_Left | LED_Position_Right_Alternating, led_status_color(LED_Status_Ready, LED_MIN_INTENSITY), LED_Delay_MS_200, 2);
    }
    else
    {
        led_blink(LED_Position_Left | LED_Position_Right_Alternating, led_status_color(LED_Status_Error, LED_MIN_INTENSITY), LED_Delay_MS_200, 2);
    }

	battery_disable();
	timer_init();
	sei();
	
	// read LED data from EEPROM
    eeprom_read_block(&led1, &ee_led1, sizeof(LED_Data));
    eeprom_read_block(&led2, &ee_led2, sizeof(LED_Data));
	
    while (1)
    {	
        LED_SOF();
        led_data(led1);
        led_data(led2);
        LED_EOF();

		if(PORTA.IN & SWITCH)
		{
			led_blink(LED_Position_Left | LED_Position_Right_Alternating, led_status_color(LED_Status_Ready, LED_MIN_INTENSITY), LED_Delay_MS_100, 0);
			
			switch_count++;
			last_button_press = systick;
			
			while(PORTA.IN & SWITCH)
			{
				if((systick - last_button_press) > SWITCH_SYSTEM_OFF_TIME_MS)
				{
					led_blink(LED_Position_Left | LED_Position_Right_Alternating, led_status_color(LED_Status_Ready,   LED_MIN_INTENSITY), LED_Delay_MS_500, 0);
					led_blink(LED_Position_Left | LED_Position_Right_Alternating, led_status_color(LED_Status_Warning, LED_MIN_INTENSITY), LED_Delay_MS_500, 0);
					led_blink(LED_Position_Left | LED_Position_Right_Alternating, led_status_color(LED_Status_Error,   LED_MIN_INTENSITY), LED_Delay_MS_500, 0);
					system_shutdown();
				}
			}
		}

        if((switch_count > 0) && ((systick - last_button_press) > SWITCH_COMMAND_EXECUTE_MS))
        {
			if(switch_count == 1)
			{
				switch_count = 0;
			}
			else
			{
				execute_command = switch_count;
				switch_count = 0;
			}
        }
		
		if(execute_command)
		{	
			LED_Position position = LED_Position_Left;
			LED_Data *led;
			do 
			{
				if(position == LED_Position_Left)
				{
                    led = &led1;
                    led_blink(LED_Position_Left, led_status_color(LED_Status_Ready, LED_MIN_INTENSITY), LED_Delay_MS_500, 1);
				}
				else
				{
    				led = &led2;
					led_blink(LED_Position_Right, led_status_color(LED_Status_Ready, LED_MIN_INTENSITY), LED_Delay_MS_500, 1);
				}
				
				if(PORTA.IN & SWITCH)
				{
					_delay_ms(10);

                    if(position == LED_Position_Left)
                    {
                        position = LED_Position_Right;
                    }
                    else
                    {
                        position = LED_Position_Left;
                    }
                    last_button_press = systick;
				}

			} while ((systick - last_button_press) < SWITCH_COMMAND_EXECUTE_MS);
			
			switch (execute_command)
			{
				case 2:
					while(!(PORTA.IN & SWITCH))
					{
                        led->red++;
                        led_color(position, *led);
                        _delay_ms(COLOR_FADE_DELAY_MS);
					}
                    break;
				case 3:
				    while(!(PORTA.IN & SWITCH))
				    {
    				    led->green++;
    				    led_color(position, *led);
    				    _delay_ms(COLOR_FADE_DELAY_MS);
				    }
                    break;
				case 4:
					while(!(PORTA.IN & SWITCH))
					{
    					led->blue++;
    					led_color(position, *led);
    					_delay_ms(COLOR_FADE_DELAY_MS);
					}
                    break;
				case 5:
					while(!(PORTA.IN & SWITCH))
					{
    					led->intensity++;

                        if(led->intensity > LED_MAX_INTENSITY)
                        {
                            led->intensity = LED_MIN_INTENSITY;
                        }

    					led_color(position, *led);
    					_delay_ms(COLOR_INTENSITY_DELAY_MS);
					}
                    break;
				default:
					led_blink(LED_Position_Left | LED_Position_Right, led_status_color(LED_Status_Error, LED_MIN_INTENSITY), LED_Delay_MS_500, 4);
				break;
			}

            #ifdef ENABLE_EEPROM_WRITE
                if(position == LED_Position_Left)
                {
                    eeprom_write_block(&led1, &ee_led1, sizeof(LED_Data));
                }
                else
                {
                    eeprom_write_block(&led2, &ee_led2, sizeof(LED_Data));
                }
            #endif

			led_blink(LED_Position_Left | LED_Position_Right_Alternating, led_status_color(LED_Status_Ready, LED_MIN_INTENSITY), LED_Delay_MS_500, 2);

			execute_command = 0;
			switch_count = 0;
		}
    }
}

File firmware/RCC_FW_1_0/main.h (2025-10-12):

/**
 * @file main.h
 * @brief Main header file for RCC firmware.
 *
 * Defines core macros, includes, and configuration constants used throughout the RCC embedded system project. This header provides CPU frequency, switch timing constants, delay intervals, and feature switches. It also includes key AVR libraries and modular headers for system, battery, and LED functionality.
 *
 * @author g.raf
 * @date 2025-09-28
 * @version 1.0 Release
 * @copyright
 * Copyright (c) 2025 g.raf
 * Released under the GPLv3 License. (see LICENSE in repository)
 *
 * @note This file is part of the RCC AVR embedded project and subject to the repository license. For updates and revision history, please visit the GitHub repository.
 *
 * @see https://github.com/0x007e/rcc "RCC - RGB LED Color Cube"
 */

#ifndef MAIN_H_
#define MAIN_H_

	#ifndef F_CPU
        /**
         * @def F_CPU
         * @brief System clock frequency definition.
         *
         * @details
         * This macro defines the operating frequency of the microcontroller's clock in Hertz. It is used by delay functions and timing calculations. The value should match the actual hardware clock frequency to ensure correct timing behavior in the software.
         */
        #define F_CPU 20000000UL
    #endif
	
	#ifndef SWITCH
		/**
		 * @def SWITCH
		 * @brief Pin mask for the user switch/button input.
		 *
		 * @details
		 * Defines the bit mask for the hardware input pin connected to the user switch. It is used to detect button press events in the firmware.
		 */
		#define SWITCH PIN7_bm
	#endif

	#ifndef SWITCH_COMMAND_EXECUTE_MS
		/**
		 * @def SWITCH_COMMAND_EXECUTE_MS
		 * @brief Time window to finalize switch command execution in milliseconds.
		 *
		 * @details
		 * Defines the maximum duration to wait for button press sequences before executing the corresponding command. Used to handle multi-press functionality within this millisecond timeout.
		 */
		#define SWITCH_COMMAND_EXECUTE_MS 3000UL
	#endif

	#ifndef SWITCH_SYSTEM_OFF_TIME_MS
		/**
		 * @def SWITCH_SYSTEM_OFF_TIME_MS
		 * @brief Duration of button press to trigger system shutdown, in milliseconds.
		 *
		 * @details
		 * If the user holds the button for this time period, the system initiates a controlled shutdown sequence.
		 */
		#define SWITCH_SYSTEM_OFF_TIME_MS 3000UL
	#endif

	#ifndef COLOR_FADE_DELAY_MS
		/**
		 * @def COLOR_FADE_DELAY_MS
		 * @brief Delay duration for color fading effect in milliseconds.
		 *
		 * @details
		 * Controls the time interval between incremental color changes during LED color fading operations.
		 */
		#define COLOR_FADE_DELAY_MS 10UL
	#endif

	#ifndef COLOR_INTENSITY_DELAY_MS
		/**
		 * @def COLOR_INTENSITY_DELAY_MS
		 * @brief Delay duration for intensity changes in milliseconds.
		 *
		 * @details
		 * Defines the interval timing for changes in LED intensity during brightness adjustment routines.
		 */
		#define COLOR_INTENSITY_DELAY_MS 350UL
	#endif

	#ifndef ENABLE_EEPROM_WRITE
		/**
		 * @def ENABLE_EEPROM_WRITE
		 * @brief Enables EEPROM write support.
		 *
		 * @details
		 * When defined, the firmware supports writing updated LED configuration data to EEPROM. If undefined, EEPROM writes are disabled to protect memory from unnecessary wear.
		 */
		#define ENABLE_EEPROM_WRITE
	#endif

	#include <avr/io.h>
	#include <avr/sleep.h>
	#include <avr/interrupt.h>
	#include <avr/eeprom.h>
	#include <util/delay.h>

	#include "./hal/avr0/system/system.h"
	#include "./battery/battery.h"
	#include "./led/led.h"

#endif /* MAIN_H_ */

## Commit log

2025-09-29 Change value of R3
    [RCC.kicad_pcb, RCC.kicad_sch]
2025-10-03 Add assembly explosion
    [housing.FCStd]
2025-10-03 Change PCB
    [housing.FCStd]
2025-10-04 Fix ERC error
    [RCC.kicad_sch]
2025-10-04 Center the PCB in the middle of the drawing sheet
    [RCC.kicad_pcb]
2025-10-04 Upscale the pcb for better readability
2025-10-04 Optimize fabrication text position
    [RCC.kicad_pcb]
2025-10-04 Add text variables to pcb
    [RCC.kicad_pcb]
2025-10-07 Change partlist vendors
    [RCC.kicad_pcb, RCC.kicad_sch]
2025-10-12 Add dimensioning to test points
    [RCC.kicad_pcb]
2025-10-27 Add value to BOM
2025-10-29 Extend PTS530 fabrication layer
    [RCC.kicad_pcb]
2025-10-30 Add documentation
    [mechanicalsteps.de.csv, mechanicalsteps.en.csv]
2025-11-10 Add washers
    [housing.FCStd]
2025-11-11 Change rgb led color
2025-11-11 Ignore single button press
2025-11-13 Change battery empty value

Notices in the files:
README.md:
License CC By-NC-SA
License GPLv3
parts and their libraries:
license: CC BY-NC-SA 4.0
